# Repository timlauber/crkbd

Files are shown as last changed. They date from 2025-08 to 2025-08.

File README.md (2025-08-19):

# Corne keyboard

The Corne keyboard is a split keyboard with 3x6 column staggered keys
and 3 thumb keys, based on [Helix](https://github.com/MakotoKurauchi/helix).
Crkbd stands for Corne Keyboard.

## Lineup

- corne-chocolate:
  Hotswappable Corne for Chocolate switches using Kailh PCB hot-swap sockets.

## Photos

coming soon...

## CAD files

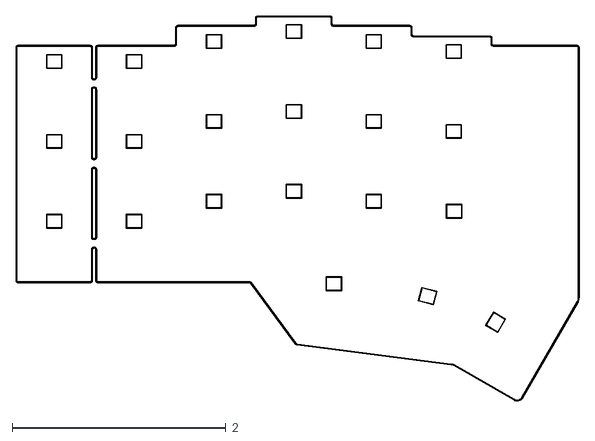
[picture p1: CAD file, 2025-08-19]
corne-chocolate/pcb/output/corne-chocolate-Edge_Cuts.dxf
5.27 x 3.60

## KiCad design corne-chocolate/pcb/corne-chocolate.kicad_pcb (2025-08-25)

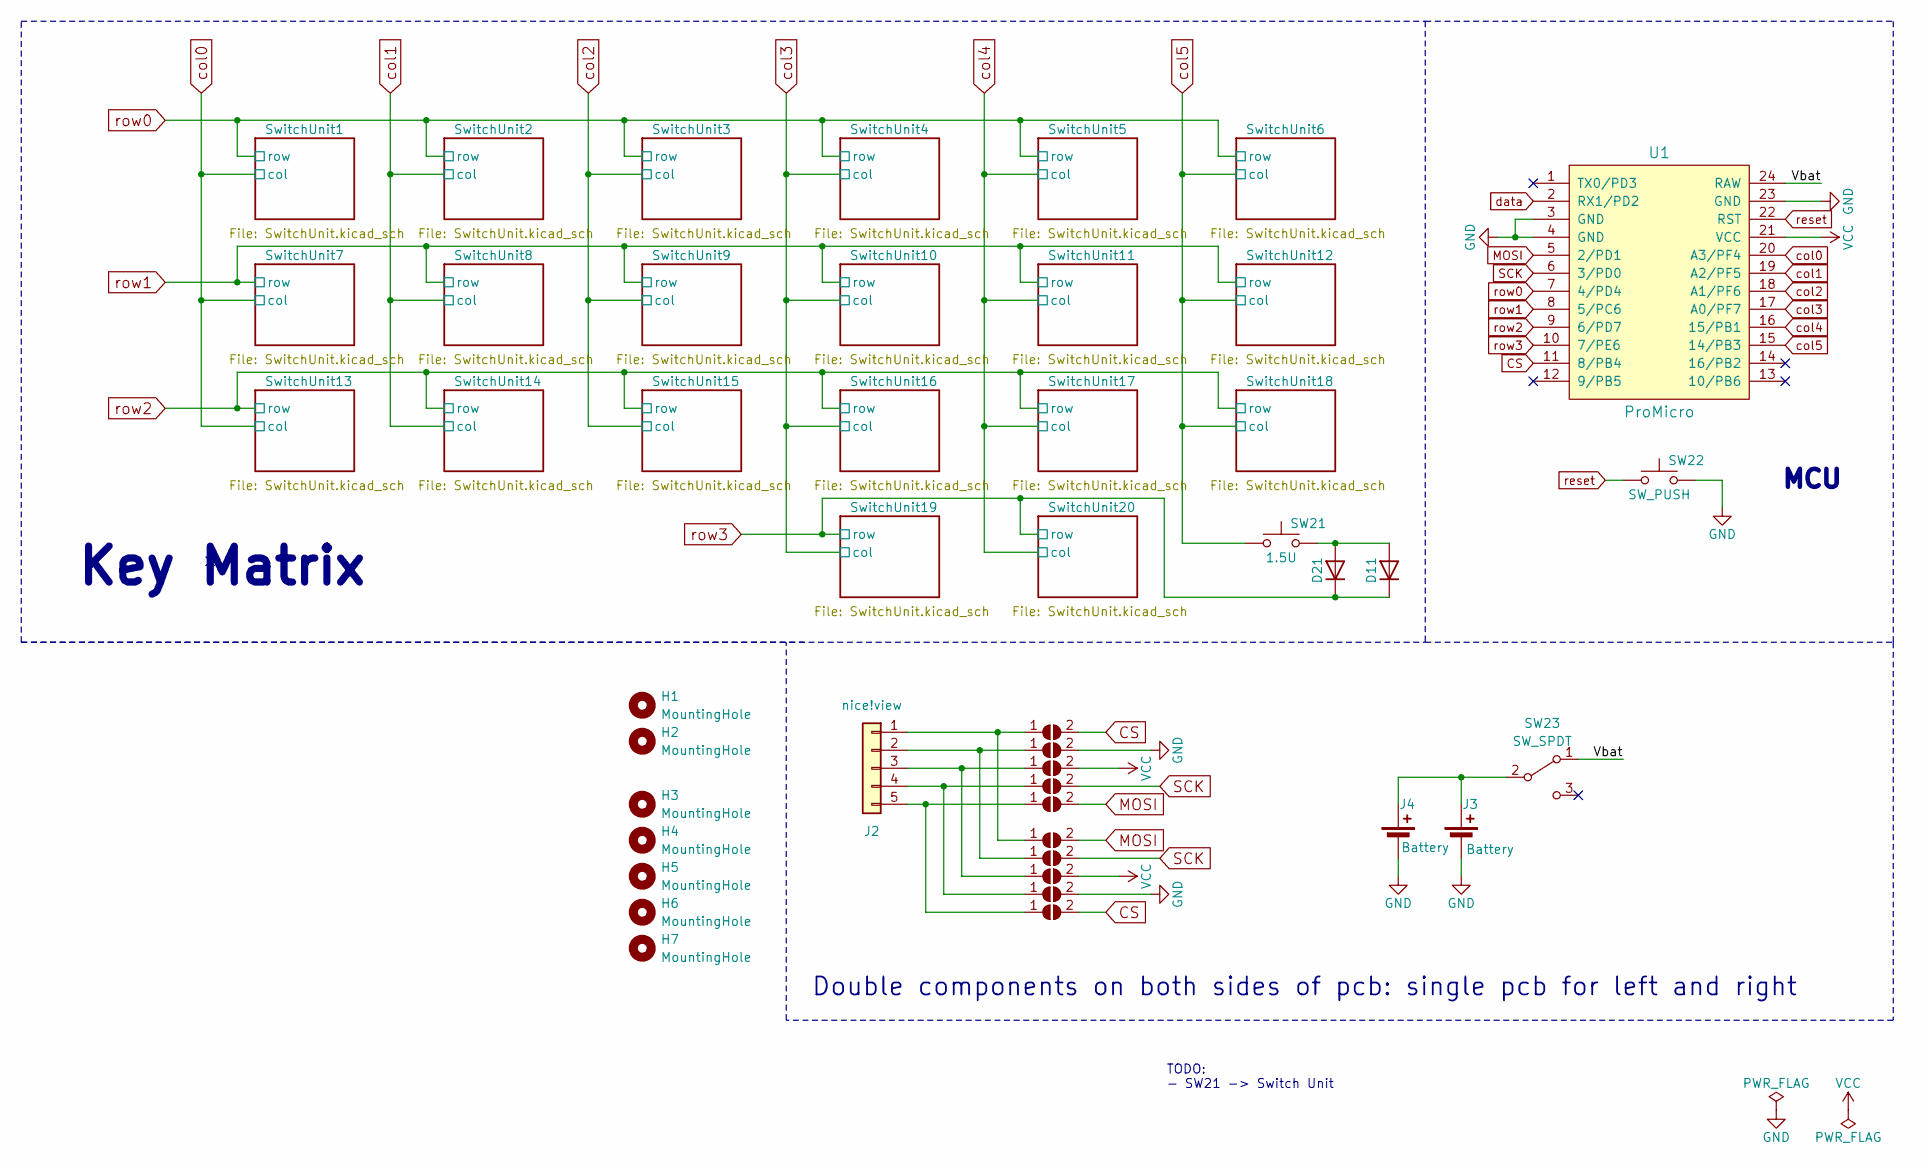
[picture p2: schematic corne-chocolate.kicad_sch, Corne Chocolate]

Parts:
D11, D21: 1N4148; D_SOD-323_HandSoldering
H1, H2: MountingHole; MountingHole_2.2mm_M2
H3, H4, H5, H6, H7: MountingHole; MountingHole_4.3mm_M4
J2: nice!view; PinHeader_1x05_P2.54mm_Vertical
J3, J4: Battery; JST_PH_S2B-PH-SM4-TB_1x02-1MP_P2.00mm_Horizontal
JP2, JP3, JP4, JP5, JP6, JP7, JP8, JP9, JP10, JP11: SolderJumper_2_Open; R_0603_1608Metric
SW21: 1.5U; Choc_Hotswap_1.5u
SW22: SW_PUSH; ResetSW
SW23: SW_SPDT; ECE_ESP2010
U1: ProMicro; ProMicro_v2

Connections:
/Vbat: SW23.1 (A), U1.24 (RAW)
CS: JP2.2 (B), JP11.2 (B), U1.11 (8/PB4)
GND: J3.2 (-), J4.2 (-), JP3.2 (B), JP10.2 (B), SW22.2, U1.3 (GND), U1.4 (GND), U1.23 (GND)
MOSI: JP6.2 (B), JP7.2 (B), U1.5 (2/PD1)
unnamed: D11.2 (A), D21.2 (A), SW21.2
unnamed: J2.1, JP2.1 (A), JP7.1 (A)
unnamed: J2.2, JP3.1 (A), JP8.1 (A)
unnamed: J2.3, JP4.1 (A), JP9.1 (A)
unnamed: J2.4, JP5.1 (A), JP10.1 (A)
unnamed: J2.5, JP6.1 (A), JP11.1 (A)
unnamed: J3.1 (+), J4.1 (+), SW23.2 (B)
SCK: JP5.2 (B), JP8.2 (B), U1.6 (3/PD0)
VCC: JP4.2 (B), JP9.2 (B), U1.21 (VCC)
col0: U1.20 (A3/PF4); also elsewhere on the board
col1: U1.19 (A2/PF5); also elsewhere on the board
col2: U1.18 (A1/PF6); also elsewhere on the board
col3: U1.17 (A0/PF7); also elsewhere on the board
col4: U1.16 (15/PB1); also elsewhere on the board
col5: SW21.1, U1.15 (14/PB3); also elsewhere on the board
data: U1.2 (RX1/PD2)
reset: SW22.1, U1.22 (RST)
row0: U1.7 (4/PD4); also elsewhere on the board
row1: U1.8 (5/PC6); also elsewhere on the board
row2: U1.9 (6/PD7); also elsewhere on the board
row3: D11.1 (K), D21.1 (K), U1.10 (7/PE6); also elsewhere on the board

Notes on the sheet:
MCU
Double components on both sides of pcb: single pcb for left and right
Key Matrix
TODO: - SW21 -> Switch Unit

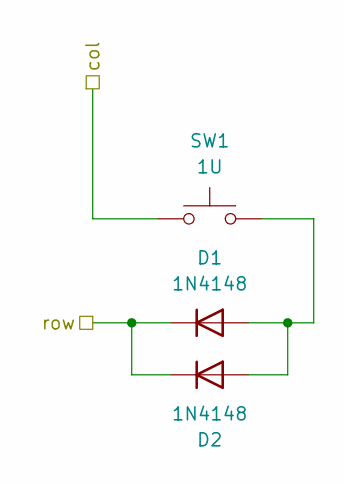
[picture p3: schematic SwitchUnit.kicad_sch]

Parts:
D1, D2: 1N4148; D_SOD-323_HandSoldering
SW1: 1U; Choc_Hotswap

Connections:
unnamed: D1.2 (A), D2.2 (A), SW1.2
col0: SW1.1; also elsewhere on the board
row0: D1.1 (K), D2.1 (K); also elsewhere on the board

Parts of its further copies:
D3, D4, D5, D6, D7, D8, D9, D10, D13, D14, D15, D22, D23, D24, D25, D26, D27, D28, D29, D30, D31, D32, D33, D34, D35, D36, D37, D38, D39, D40, D41, D42, D43, D44, D45, D46, D47, D48: 1N4148; D_SOD-323_HandSoldering
SW2, SW3, SW4, SW5, SW6, SW7, SW8, SW9, SW10, SW11, SW12, SW13, SW14, SW15, SW16, SW17, SW18, SW19, SW20: 1U; Choc_Hotswap

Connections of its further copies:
unnamed: D3.2 (A), D9.2 (A), SW4.2
unnamed: D4.2 (A), D5.2 (A), SW19.2
unnamed: D6.2 (A), D10.2 (A), SW20.2
unnamed: D8.2 (A), D13.2 (A), SW8.2
unnamed: D14.2 (A), D27.2 (A), SW14.2
unnamed: D15.2 (A), D34.2 (A), SW10.2
unnamed: D22.2 (A), D23.2 (A), SW2.2
unnamed: D24.2 (A), D25.2 (A), SW7.2
unnamed: D7.2 (A), D26.2 (A), SW13.2
unnamed: D28.2 (A), D29.2 (A), SW3.2
unnamed: D30.2 (A), D31.2 (A), SW9.2
unnamed: D32.2 (A), D33.2 (A), SW15.2
unnamed: D35.2 (A), D36.2 (A), SW16.2
unnamed: D37.2 (A), D38.2 (A), SW5.2
unnamed: D39.2 (A), D40.2 (A), SW11.2
unnamed: D41.2 (A), D42.2 (A), SW17.2
unnamed: D43.2 (A), D44.2 (A), SW6.2
unnamed: D45.2 (A), D46.2 (A), SW12.2
unnamed: D47.2 (A), D48.2 (A), SW18.2
col0: SW7.1, SW13.1; also elsewhere on the board
col1: SW2.1, SW8.1, SW14.1; also elsewhere on the board
col2: SW3.1, SW9.1, SW15.1; also elsewhere on the board
col3: SW4.1, SW10.1, SW16.1, SW19.1; also elsewhere on the board
col4: SW5.1, SW11.1, SW17.1, SW20.1; also elsewhere on the board
col5: SW6.1, SW12.1, SW18.1; also elsewhere on the board
row0: D3.1 (K), D9.1 (K), D22.1 (K), D23.1 (K), D28.1 (K), D29.1 (K), D37.1 (K), D38.1 (K), D43.1 (K), D44.1 (K); also elsewhere on the board
row1: D8.1 (K), D13.1 (K), D15.1 (K), D24.1 (K), D25.1 (K), D30.1 (K), D31.1 (K), D34.1 (K), D39.1 (K), D40.1 (K), D45.1 (K), D46.1 (K); also elsewhere on the board
row2: D7.1 (K), D14.1 (K), D26.1 (K), D27.1 (K), D32.1 (K), D33.1 (K), D35.1 (K), D36.1 (K), D41.1 (K), D42.1 (K), D47.1 (K), D48.1 (K); also elsewhere on the board
row3: D4.1 (K), D5.1 (K), D6.1 (K), D10.1 (K); also elsewhere on the board

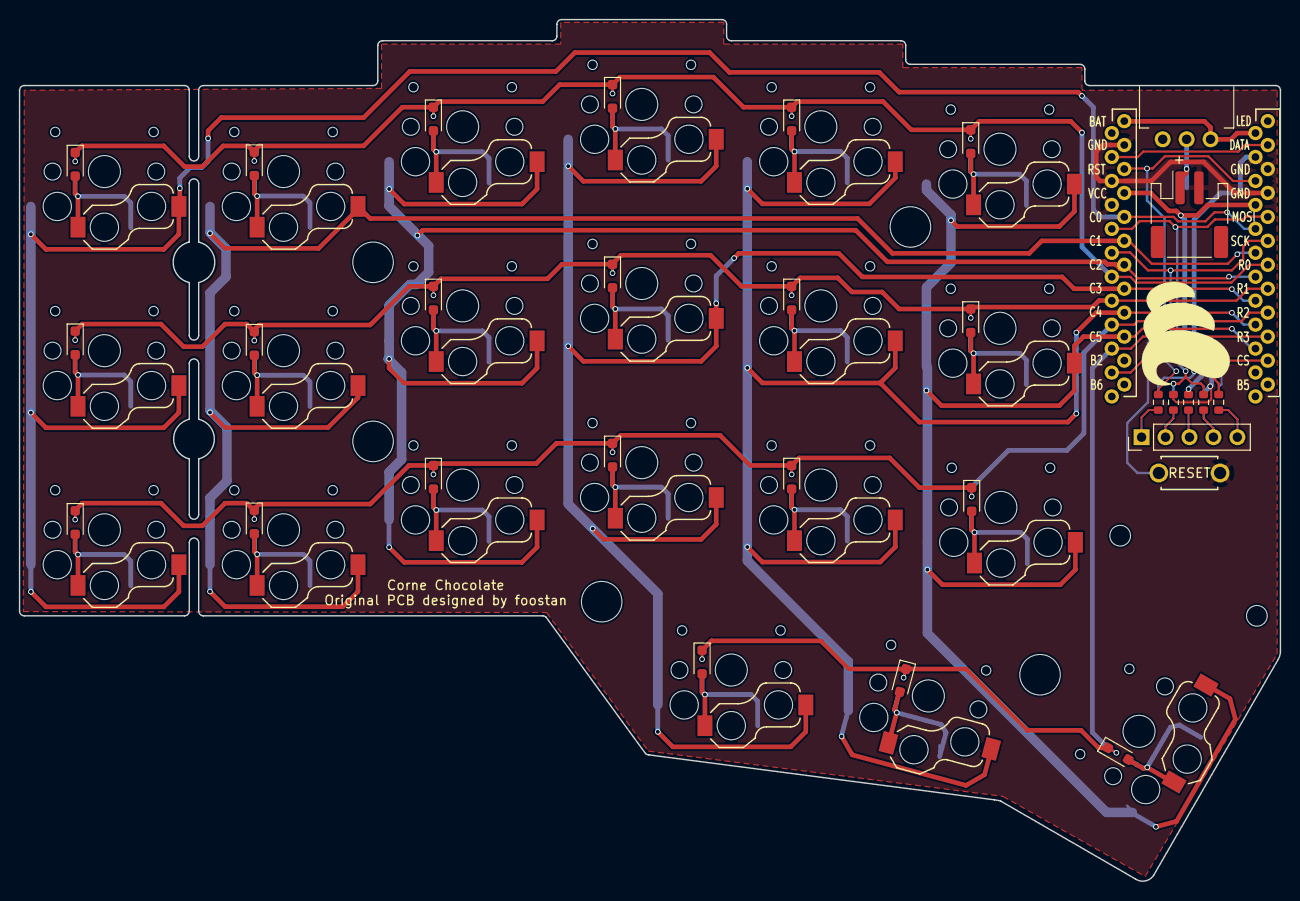
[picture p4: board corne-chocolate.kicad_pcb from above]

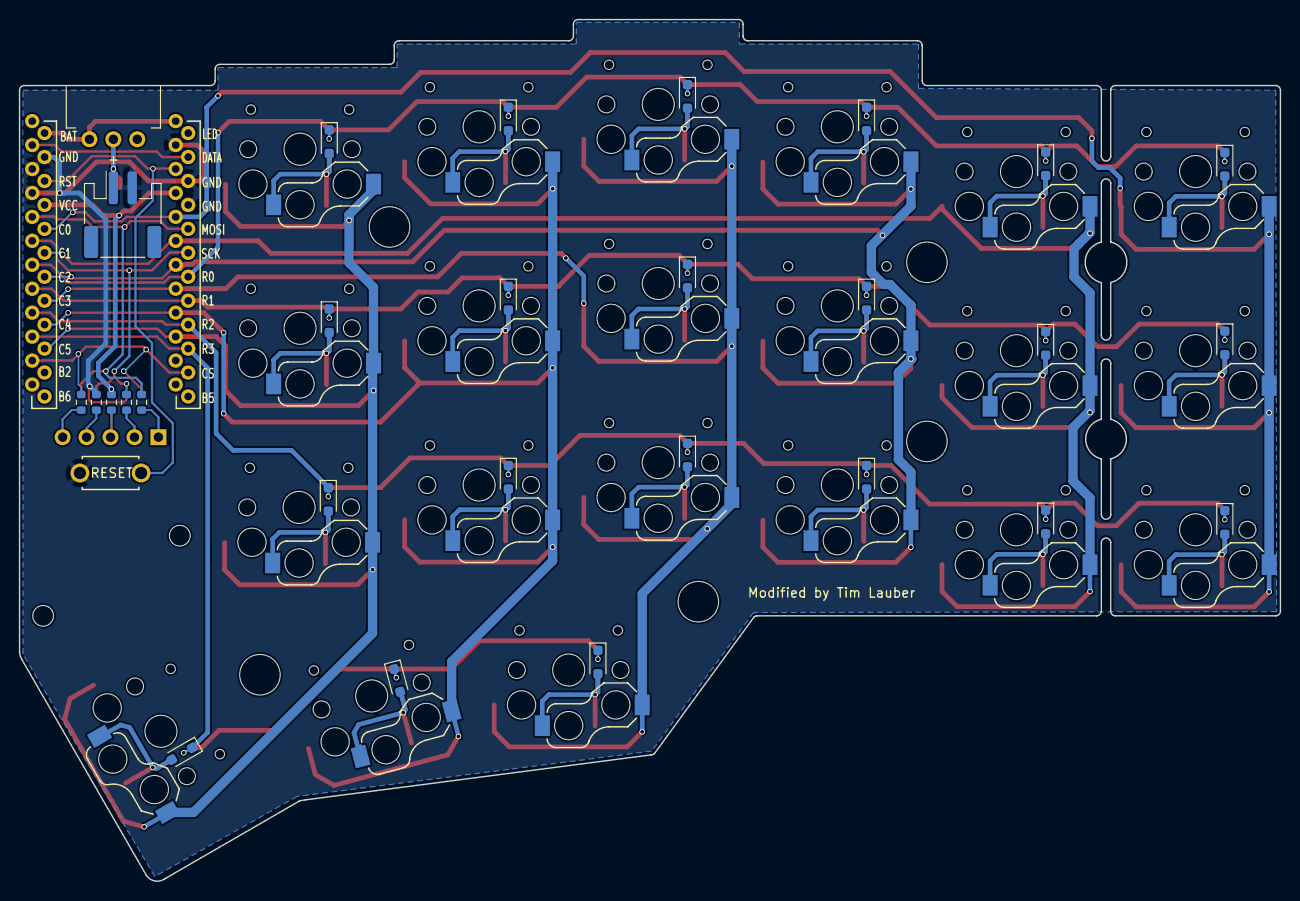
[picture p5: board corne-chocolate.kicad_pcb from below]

Board: 2 copper layers, 133.8 x 91.4 mm, 86 parts (28 on the bottom side), 44 nets.

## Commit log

2023-08-13 KiCAD7 support
    [corne-chocolate.kicad_pcb, corne-chocolate.kicad_sch]
2023-08-13 Cleanup schematic
    [corne-chocolate.kicad_sch]
2023-08-13 cleanup symbol library. copy symbols from pcb to new project specific library
    [corne-chocolate.kicad_pcb, corne-chocolate.kicad_sch]
2025-08-19 corne-chocolate first modified version by timlauber: first cleanup of schematic and layout
    [SwitchUnit.kicad_sch, corne-chocolate-Edge_Cuts.dxf, corne-chocolate.kicad_sch]
2025-08-19 Clean slate
    [corne-bottom-plate.kicad_pcb, corne-cherry.kicad_pcb, corne-cherry.kicad_sch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]
2025-08-19 pcb remove unused symbol libraries from symbol library table
2025-08-19 pcb layout -> KiCAD v9
2025-08-19 pcb change on/off switch
    [corne-chocolate.kicad_pcb, corne-chocolate.kicad_sch]
2025-08-19 pcb remove TRRS
    [corne-chocolate.kicad_pcb, corne-chocolate.kicad_sch]
2025-08-23 pcb clean up layout under MCU
    [corne-chocolate.kicad_pcb]
2025-08-23 pcb remove underglow LEDs
    [corne-chocolate.kicad_pcb, corne-chocolate.kicad_sch]
2025-08-25 pcb remove per-switch LEDs
    [SwitchUnit.kicad_sch, corne-chocolate.kicad_pcb, corne-chocolate.kicad_sch]
2025-08-25 pcb clean up mounting holes
    [corne-chocolate.kicad_pcb, corne-chocolate.kicad_sch]
2025-08-27 pcb replace SMD jumper with solder jumper
2025-08-31 pcb change corne logo to mask layer. Add my logo
2025-09-02 pcb add choc hotswap 3d model
2025-09-05 pcb change battery connector to THT
